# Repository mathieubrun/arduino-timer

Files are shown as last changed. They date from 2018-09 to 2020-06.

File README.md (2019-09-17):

# arduino timer

WIP : Built the first version of the board. Some adjustment needed, see [Lessons learned](#Lessons-learned).

## Usage

TODO

## Schema

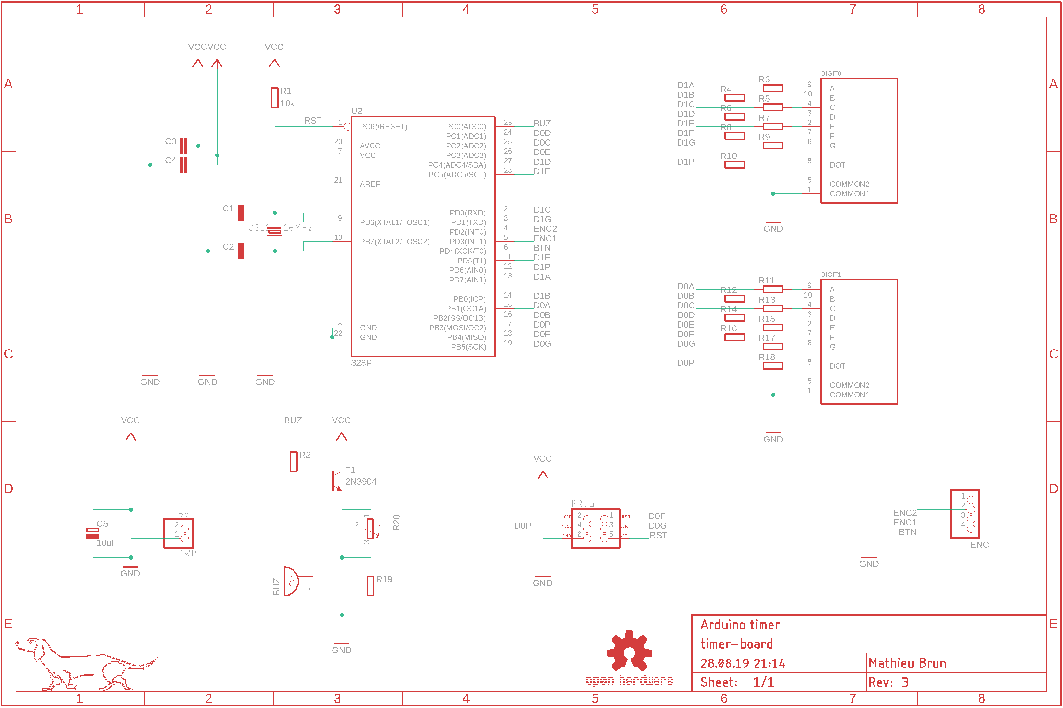
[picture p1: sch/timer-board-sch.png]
Schema


## Board

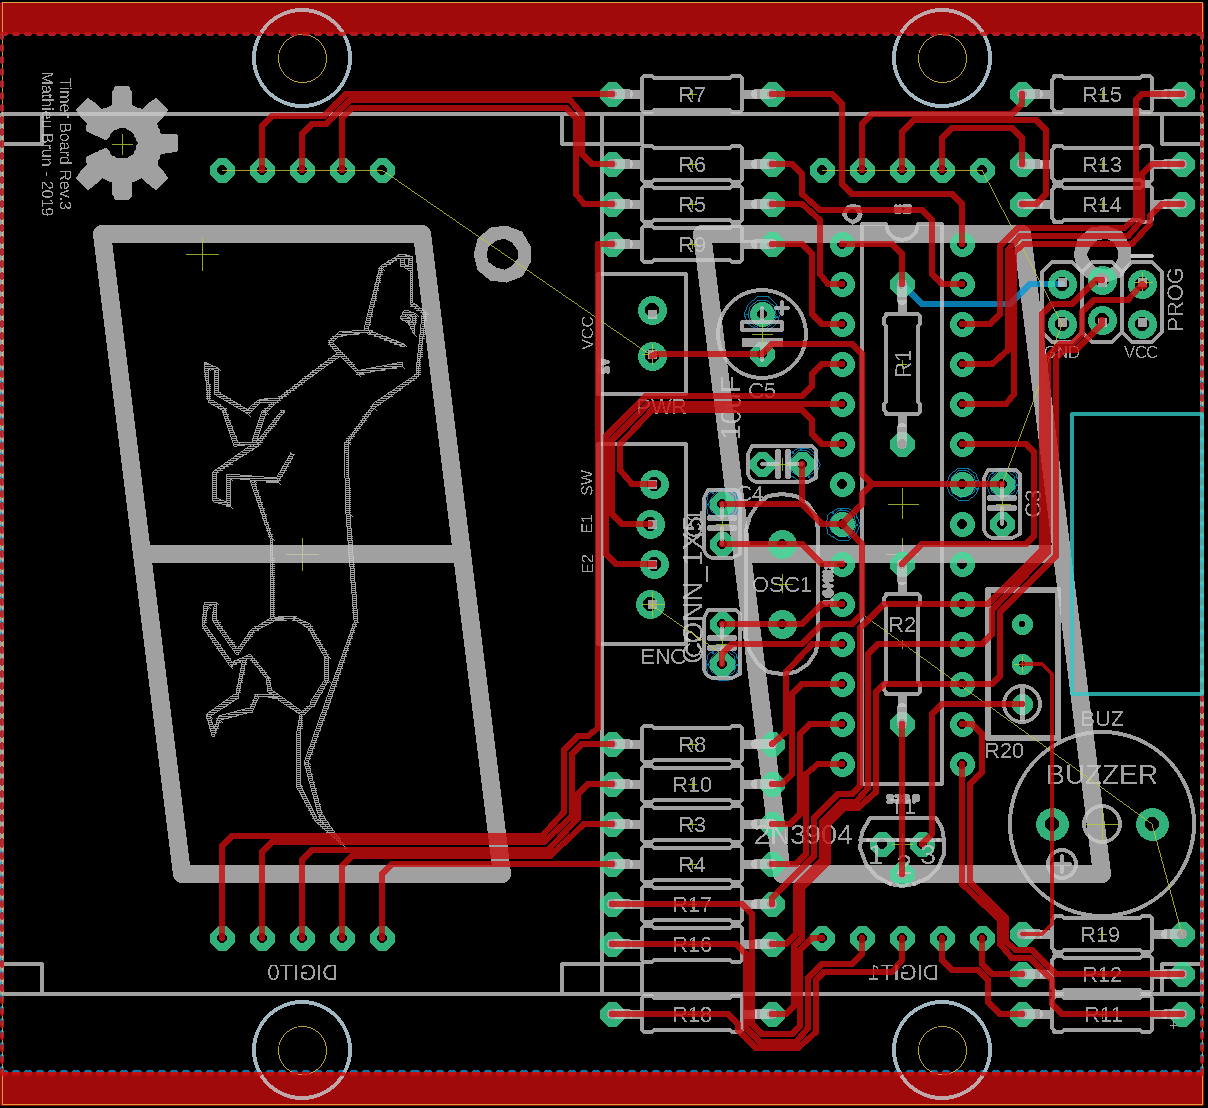
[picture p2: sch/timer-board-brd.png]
Board


## Code features

TODO

### Lessons learned

- add markings on silkscreen with polarities when applicable
- check component orientation: rev3 of the board was born because the 7 segments were upside down
- check component sizes twice: I used the wrong capacitor footprint
- check that components on both sides of the board can fit: the 7 segments display feets were on top of pads of the resistors on the other side.
- check pin pitch twice: the power connector had 1mm pitch instead of 0.1".
- check side of enclosure before cutting, twice: of course I cut the wrong side...
- for components with wiring like the encoder, double check correct soldering
- [a buzzer may require a resistor](https://electronics.stackexchange.com/questions/6500/connecting-piezo-buzzer-with-bjt) !

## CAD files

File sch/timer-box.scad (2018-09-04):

// lcd_size=[24, 34, 9];
lcd_size=[38, 56, 11.2];

battery_size=[50, 36, 12];
box_size=[95, 70, 25];
board_size=[lcd_size[0] * 2 + 1, box_size[1]-5, 3];
knob_h=15;
knob_r=12.5;
encoder_size=[15, 15, 15];
buzzer_r=8;
buzzer_h=10;

// battery
translate([-box_size[0]/2, box_size[1]/2 - battery_size[1], 0]) {
    color("black", 0.2) cube(battery_size);
}

// lcd
translate([-lcd_size[0], -lcd_size[1] / 2, box_size[2] - lcd_size[2]]) {
    translate([0 - 0.5, 0, 0]) color("white", 0.5) cube(lcd_size);
    translate([lcd_size[0] + 0.5, 0, 0]) color("white", 0.5) cube(lcd_size);
}

// board
translate([-board_size[0]/2, -board_size[1]/2, box_size[2] - lcd_size[2] - board_size[2]]) {
    color("green", 0.2) cube(board_size);
}

// knob
translate([box_size[0]/2, 0, box_size[2]/2 - 3]) {
    color("red", 0.1) rotate([0, 90, 0]) cylinder(knob_h, knob_r, knob_r);
    color("black") translate([-encoder_size[0], -encoder_size[1]/2 , -encoder_size[2]/2]) cube(encoder_size);
}

// buzzer
translate([0, -box_size[1]/2 + buzzer_r + 5, box_size[2] - lcd_size[2] - board_size[2] - buzzer_h]) {
    color("black", 0.2) cylinder(buzzer_h, buzzer_r, buzzer_r);
}

// box
translate([-box_size[0]/2, -box_size[1]/2, -3]) {
    color("blue", 0.1) cube(box_size);
}

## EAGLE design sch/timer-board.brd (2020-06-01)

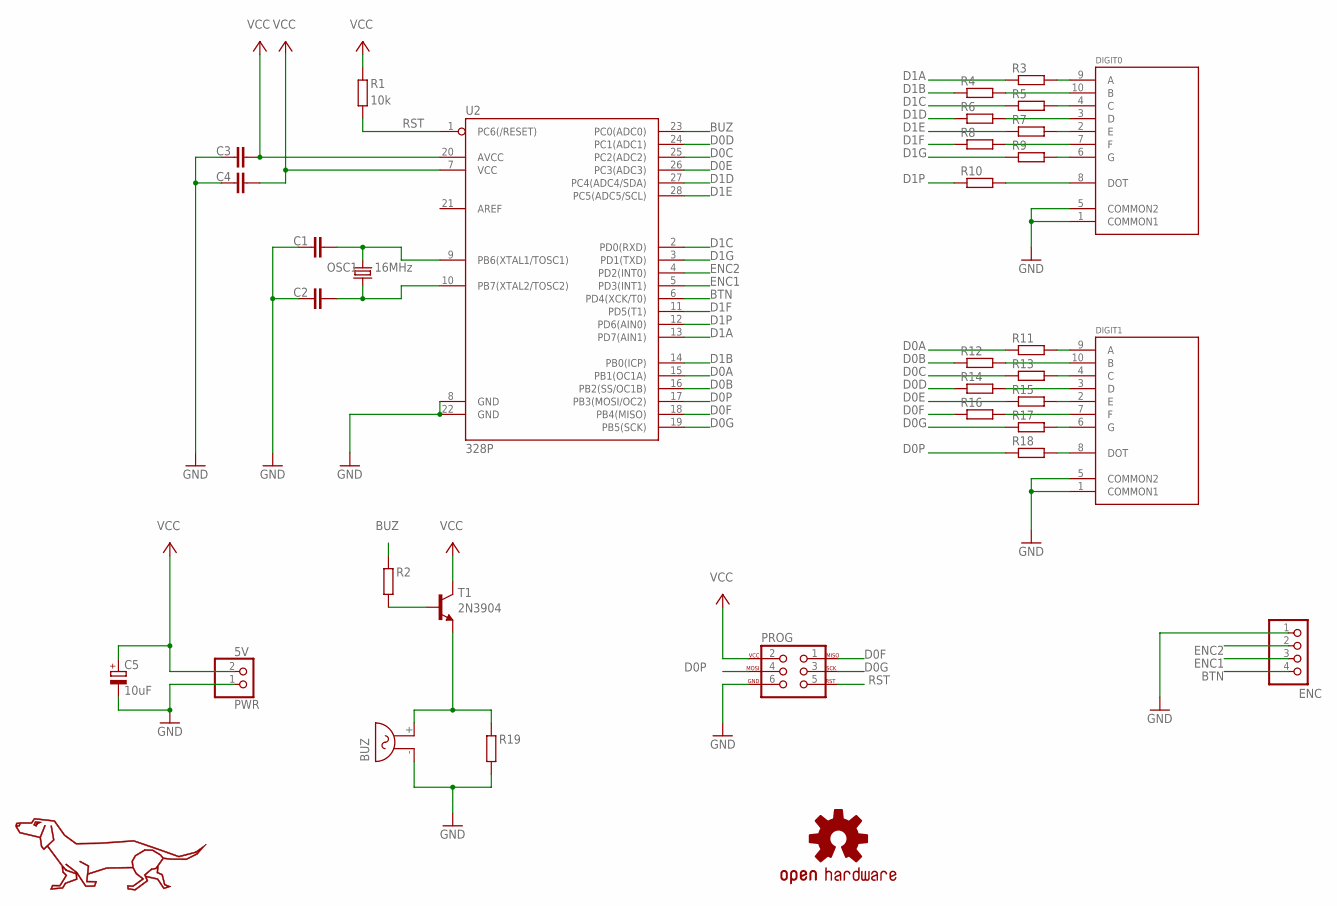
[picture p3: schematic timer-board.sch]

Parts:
BUZ: BUZZER
C1, C2: 22pF; C025-024X044
C3, C4: 0.1uF; C025-024X044
C5: 10uF; E2,5-6
DIGIT0, DIGIT1: 7_SEGMENT_DISPLAY; 7_SEGMENT_1.8_INCH
ENC: CONN_1X5; 1X04_LOCK_JST
LOGO1: OSHW-LOGOL; OSHW-LOGO-L
OSC1: 16MHz; HC49US
PROG: AVR_SPI_PROG_3X22X3_LOCK; 2X3_LOCK
PWR: 5V; 1X02_LOCK_JST
R1: 10k; 0207/10
R2, R3, R4, R5, R6, R7, R8, R9, R10, R11, R12, R13, R14, R15, R16, R17, R18, R19: R-EU_0207/10; 0207/10
T1: 2N3904; TO92
U2: 328P; DIP28
U$1: LOGO_DOG

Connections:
BTN: ENC.4, U2.6 (PD4(XCK/T0))
BUZ: R2.2, U2.23 (PC0(ADC0))
D0A: R11.1, U2.15 (PB1(OC1A))
D0B: R12.1, U2.16 (PB2(SS/OC1B))
D0C: R13.1, U2.25 (PC2(ADC2))
D0D: R14.1, U2.24 (PC1(ADC1))
D0E: R15.1, U2.26 (PC3(ADC3))
D0F: PROG.1, R16.1, U2.18 (PB4(MISO))
D0G: PROG.3, R17.1, U2.19 (PB5(SCK))
D0P: PROG.4, R18.1, U2.17 (PB3(MOSI/OC2))
D1A: R3.1, U2.13 (PD7(AIN1))
D1B: R4.1, U2.14 (PB0(ICP))
D1C: R5.1, U2.2 (PD0(RXD))
D1D: R6.1, U2.27 (PC4(ADC4/SDA))
D1E: R7.1, U2.28 (PC5(ADC5/SCL))
D1F: R8.1, U2.11 (PD5(T1))
D1G: R9.1, U2.3 (PD1(TXD))
D1P: R10.1, U2.12 (PD6(AIN0))
ENC1: ENC.3, U2.5 (PD3(INT1))
ENC2: ENC.2, U2.4 (PD2(INT0))
GND: BUZ.- (1), C1.1, C2.1, C3.2, C4.2, C5.-, DIGIT0.1 (COMMON1), DIGIT0.5 (COMMON2), DIGIT1.1 (COMMON1), DIGIT1.5 (COMMON2), ENC.1, PROG.6, PWR.1, R19.1, U2.8 (GND), U2.22 (GND)
unnamed: DIGIT0.9 (A), R3.2
unnamed: DIGIT0.10 (B), R4.2
unnamed: DIGIT0.4 (C), R5.2
unnamed: DIGIT0.3 (D), R6.2
unnamed: DIGIT0.2 (E), R7.2
unnamed: DIGIT0.7 (F), R8.2
unnamed: DIGIT0.6 (G), R9.2
unnamed: DIGIT0.8 (DOT), R10.2
unnamed: R2.1, T1.2 (B)
unnamed: DIGIT1.9 (A), R11.2
unnamed: DIGIT1.10 (B), R12.2
unnamed: DIGIT1.4 (C), R13.2
unnamed: DIGIT1.3 (D), R14.2
unnamed: DIGIT1.2 (E), R15.2
unnamed: DIGIT1.7 (F), R16.2
unnamed: DIGIT1.6 (G), R17.2
unnamed: DIGIT1.8 (DOT), R18.2
unnamed: BUZ.+ (2), R19.2, T1.3 (E)
RST: PROG.5, R1.1, U2.1 (PC6(/RESET))
VCC: C3.1, C4.1, C5.+, PROG.2, PWR.2, R1.2, T1.1 (C), U2.7 (VCC), U2.20 (AVCC)
XTAL1: C1.2, OSC1.2, U2.9 (PB6(XTAL1/TOSC1))
XTAL2: C2.2, OSC1.1, U2.10 (PB7(XTAL2/TOSC2))

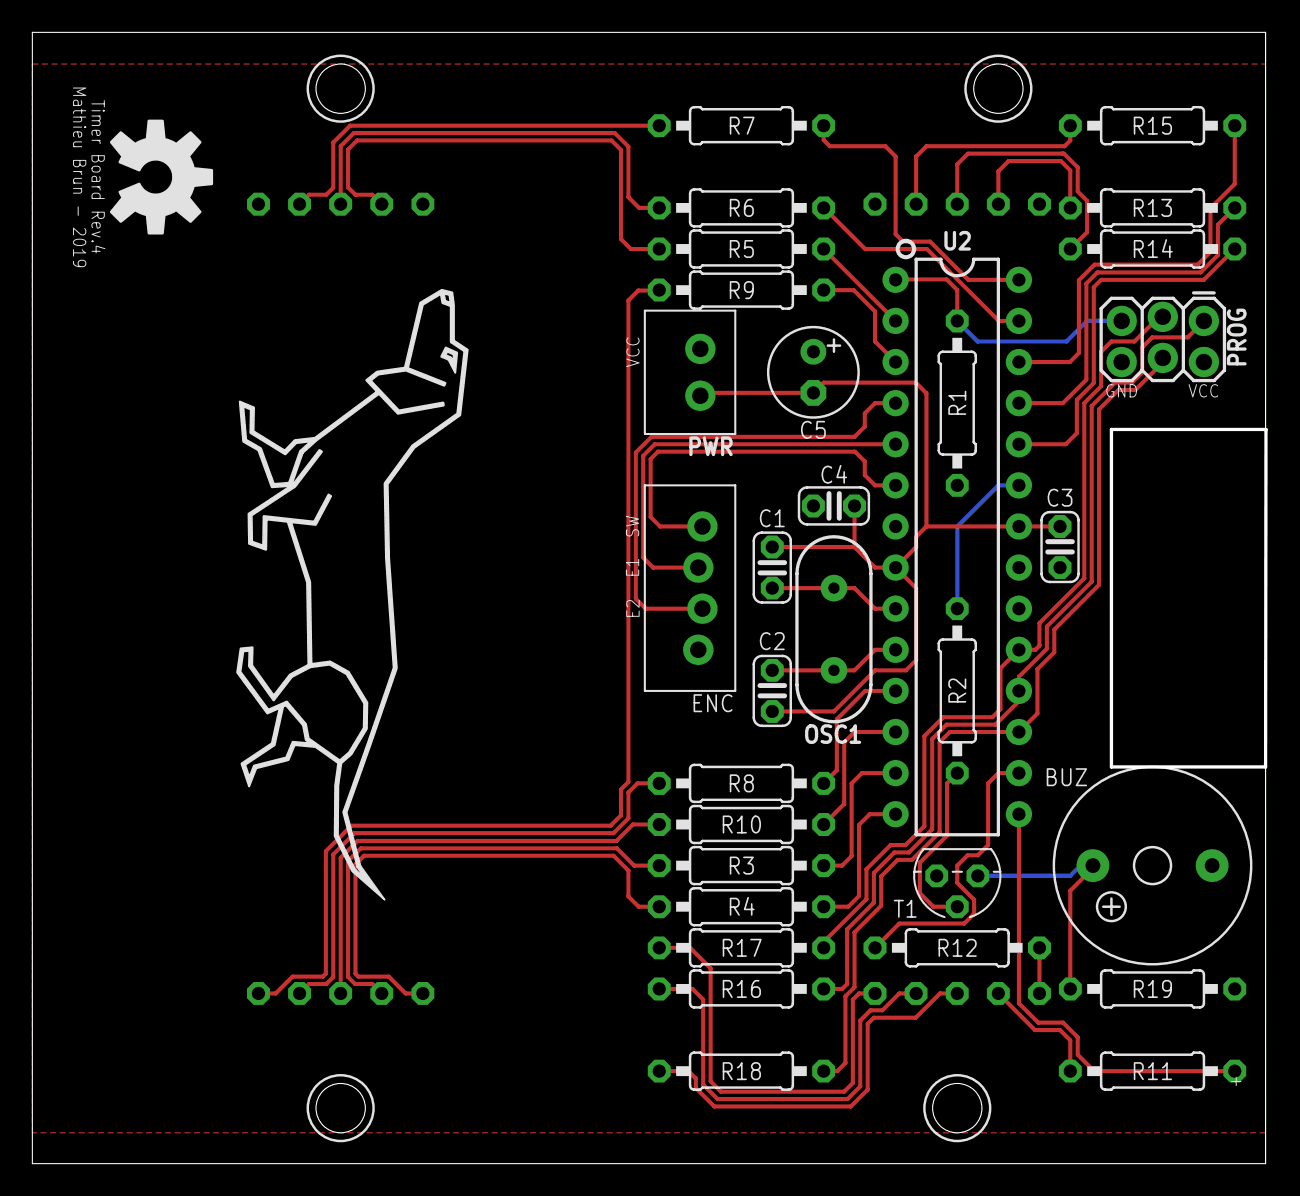
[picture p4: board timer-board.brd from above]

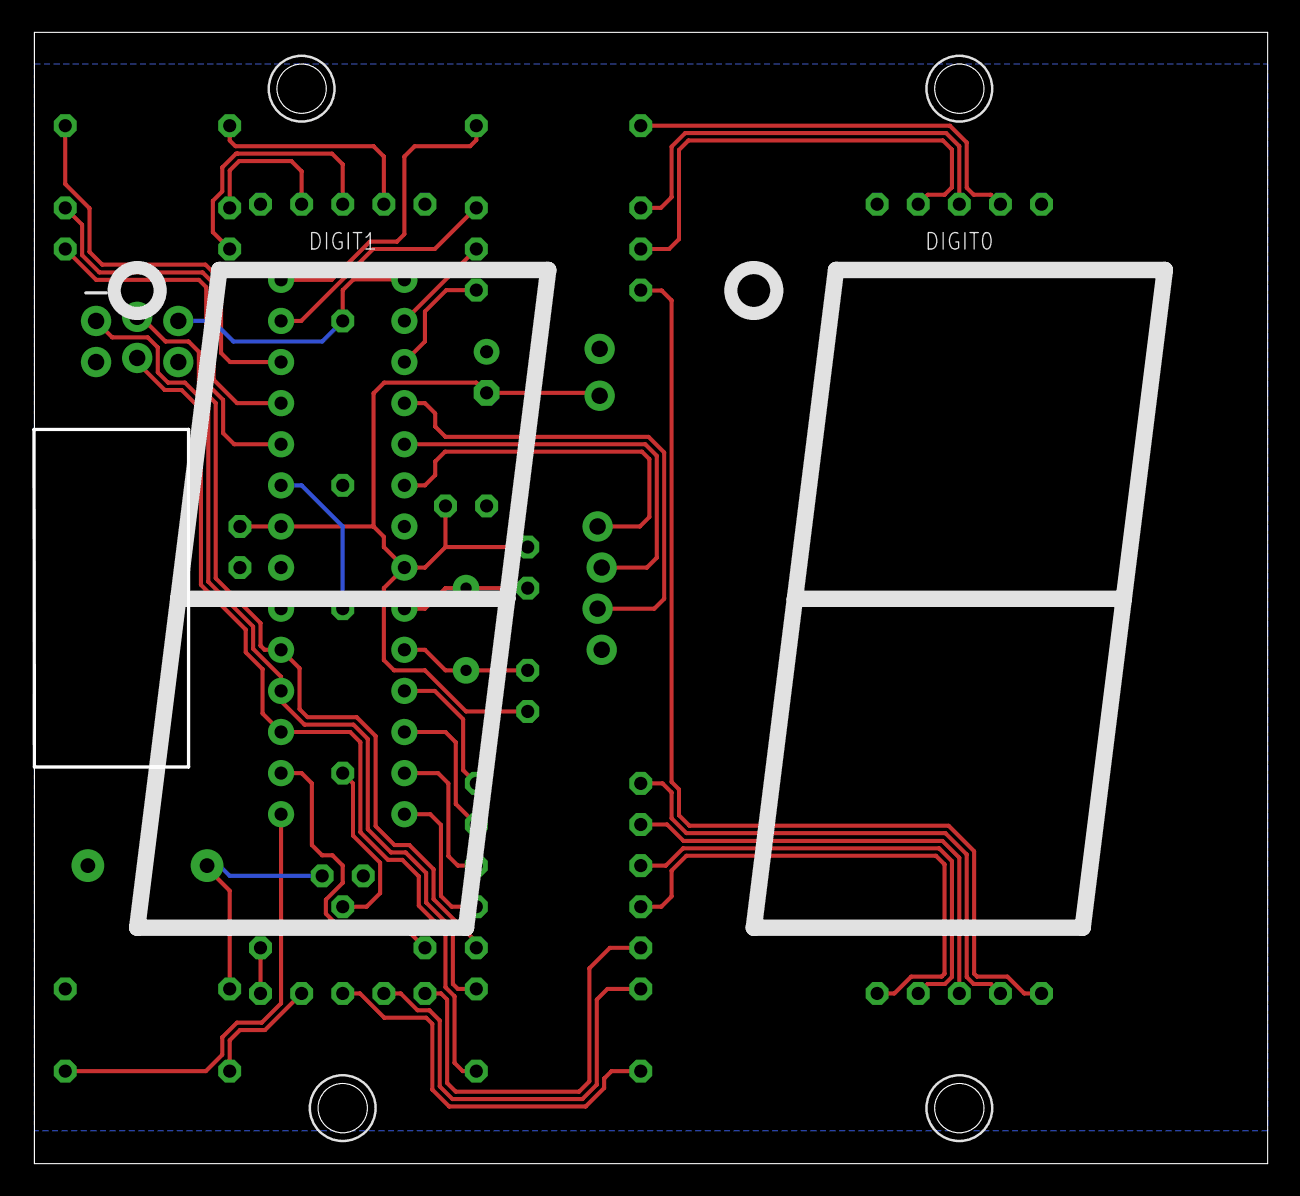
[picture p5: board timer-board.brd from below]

Board: 2 copper layers, 76.2 x 69.9 mm, 35 parts (2 on the bottom side), 43 nets.

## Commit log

2018-08-16 Added SCAD concept
    [timer-box.scad]
2018-09-04 updated concept with new sizes
    [timer-box.scad]
2018-09-04 added board schematic
    [timer-board.sch]
2018-09-05 Cleaned up schematic
    [timer-board.sch]
2018-09-15 Updated schematic to use new parts Added PCB first version
    [timer-board.brd, timer-board.sch]
2018-09-16 PCB : better label positioning
    [timer-board.brd]
2018-09-16 PCB : Added some logos
    [timer-board.brd, timer-board.sch]
2018-09-16 PCB : Fixed resistor label
    [timer-board.brd, timer-board.sch]
2018-09-17 PCB : Updated dog logo
    [timer-board.brd, timer-board.sch]
2018-09-18 SCH : Added frame
    [timer-board.sch]
2018-10-23 feat: updated board to smaller layout
    [timer-board.brd, timer-board.sch]
2018-10-23 feat: reduced board edge clearance
    [timer-board.brd]
2018-11-03 feat: pcb added holes
    [timer-board.brd]
2019-08-01 refactoring: reworked routing
    [timer-board.brd, timer-board.sch]
2019-08-09 refactoring: finalized routing
    [encoder-board.brd, encoder-board.sch, timer-board.brd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]
2019-09-17 refactoring: added vcc pour, updated capacitors footprints fix: correct orientation of 7segment displays
    [encoder-board.brd, timer-board.brd, timer-board.sch]
2020-06-01 fix: clearance around milling, moved resistors, removed buzzer resistor
    [timer-board.brd, timer-board.sch]

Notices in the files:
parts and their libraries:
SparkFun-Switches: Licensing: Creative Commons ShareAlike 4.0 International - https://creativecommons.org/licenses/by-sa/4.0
